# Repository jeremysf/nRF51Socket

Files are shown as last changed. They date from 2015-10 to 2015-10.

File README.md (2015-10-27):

# nRF51Socket
QFN48 socket to J-Link/JTAG 20-pin connector to program bootloaders, etc for Nordic nRF51.

I included a USB connector as an alternative to using the 5V power from the J-Link, but haven't had to use that yet, the power from the J-Link device works great!

I also included a 16mhz crystal in the design so that I could boot up the nRF51 and do some basic validation. Probably could get away without populating those or related components.

The socket is available on Amazon.com and Ebay.com for about $100 it's a QFN-48(52)BT-0.4-01 manufactured by Enplas.

![alt text]
(https://pbs.twimg.com/media/CR9HupoUYAArvvp.jpg)

![alt text]
(https://pbs.twimg.com/media/CR9HuqqVAAADbZV.jpg)

![alt text]
(https://pbs.twimg.com/media/CR9HuqIVAAAAnUr.jpg)

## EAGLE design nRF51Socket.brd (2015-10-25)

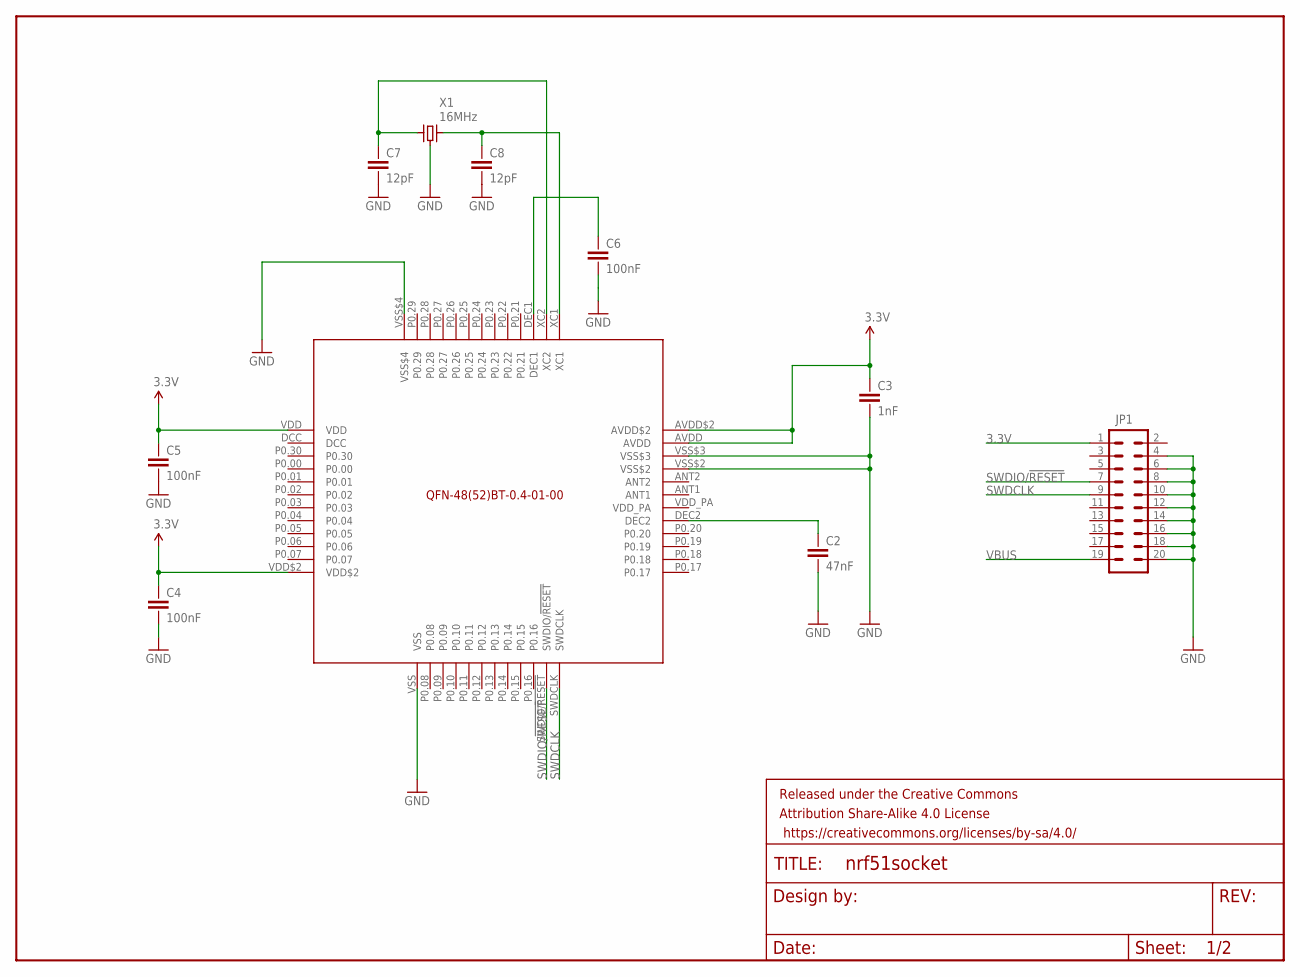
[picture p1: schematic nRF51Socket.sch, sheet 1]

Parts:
C2: 47nF; CAP-403
C3: 1nF; CAP-403
C4, C5, C6: 100nF; CAP-403
C7, C8: 12pF; CAP-403
FRAME1: FRAME-LETTERNO_PACKAGE; DUMMY
JP1: M10X2; 2X10
U1: QFN-48(52)BT-0.4-01-00
X1: 16MHz; CRYSTAL-2520

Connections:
3.3V: C3.2 (1), C4.2 (1), C5.2 (1), JP1.1, U1.AVDD, U1.AVDD$2, U1.VDD, U1.VDD$2; also elsewhere on the board
GND: C2.1 (2), C3.1 (2), C4.1 (2), C5.1 (2), C6.1 (2), C7.1 (2), C8.1 (2), JP1.4, JP1.6, JP1.8, JP1.10, JP1.12, JP1.14, JP1.16, JP1.18, JP1.20, U1.VSS, U1.VSS$2, U1.VSS$3, U1.VSS$4, X1.GND@1 (GND), X1.GND@2 (GND); also elsewhere on the board
unnamed: C2.2 (1), U1.DEC2
unnamed: C6.2 (1), U1.DEC1
unnamed: C8.2 (1), U1.XC1, X1.3
unnamed: C7.2 (1), U1.XC2, X1.1
SWDCLK: JP1.9, U1.SWDCLK
SWDIO/!RESET: JP1.7, U1.SWDIO/!RESET
VBUS: JP1.19; also elsewhere on the board

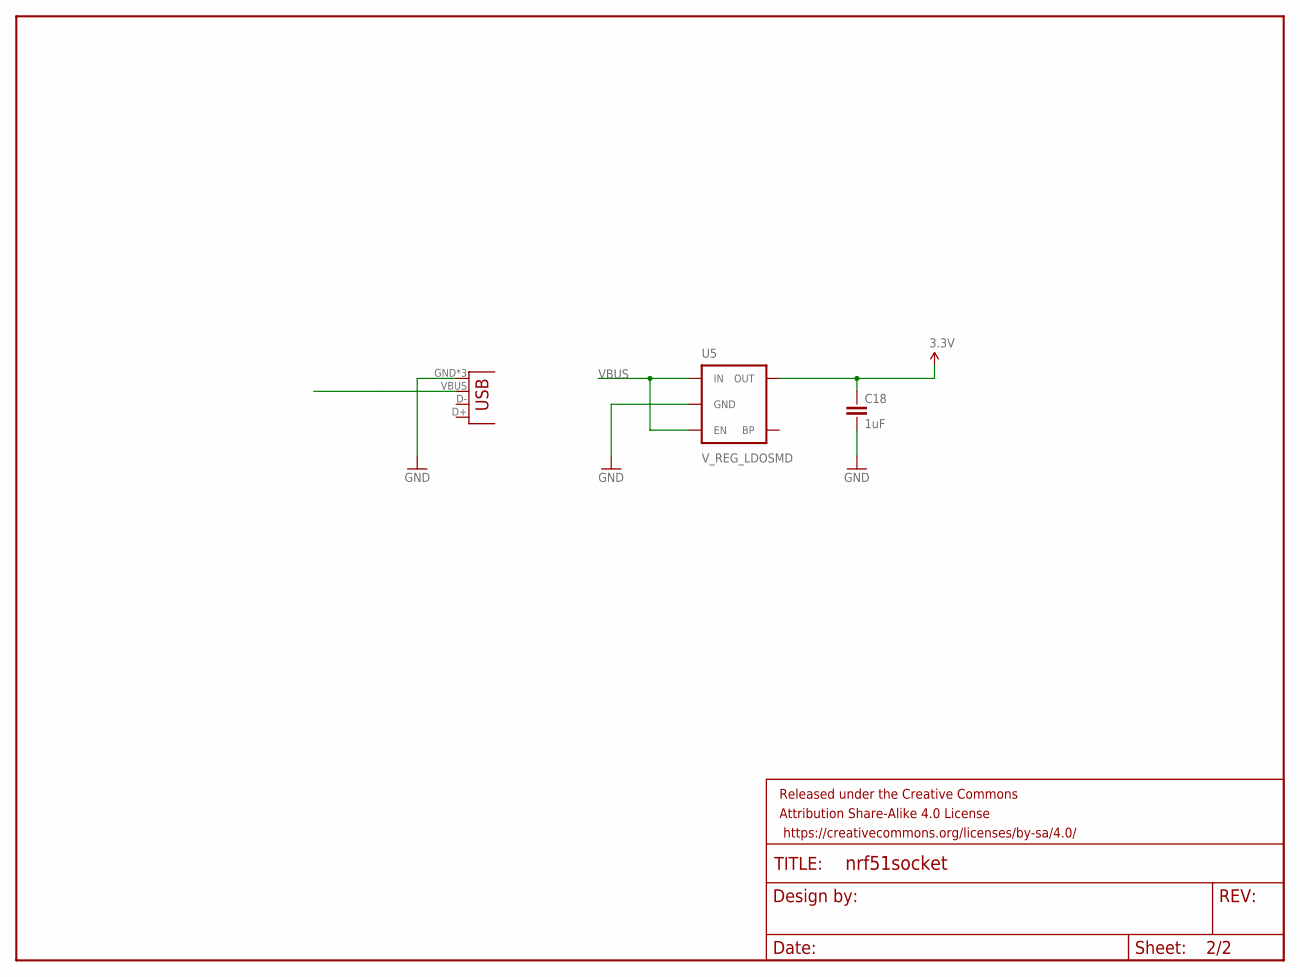
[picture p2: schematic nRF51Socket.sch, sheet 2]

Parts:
C18: 1uF; CAP-403
FRAME2: FRAME-LETTERNO_PACKAGE; DUMMY
JP2: USB-MICROB
U5: V_REG_LDOSMD; SOT23-5

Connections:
3.3V: C18.2 (1), U5.5 (OUT); also elsewhere on the board
GND: C18.1 (2), JP2.GND, JP2.MT1 (GND), JP2.MT2 (GND), U5.2 (GND); also elsewhere on the board
VBUS: JP2.VBUS, U5.1 (IN), U5.3 (EN); also elsewhere on the board

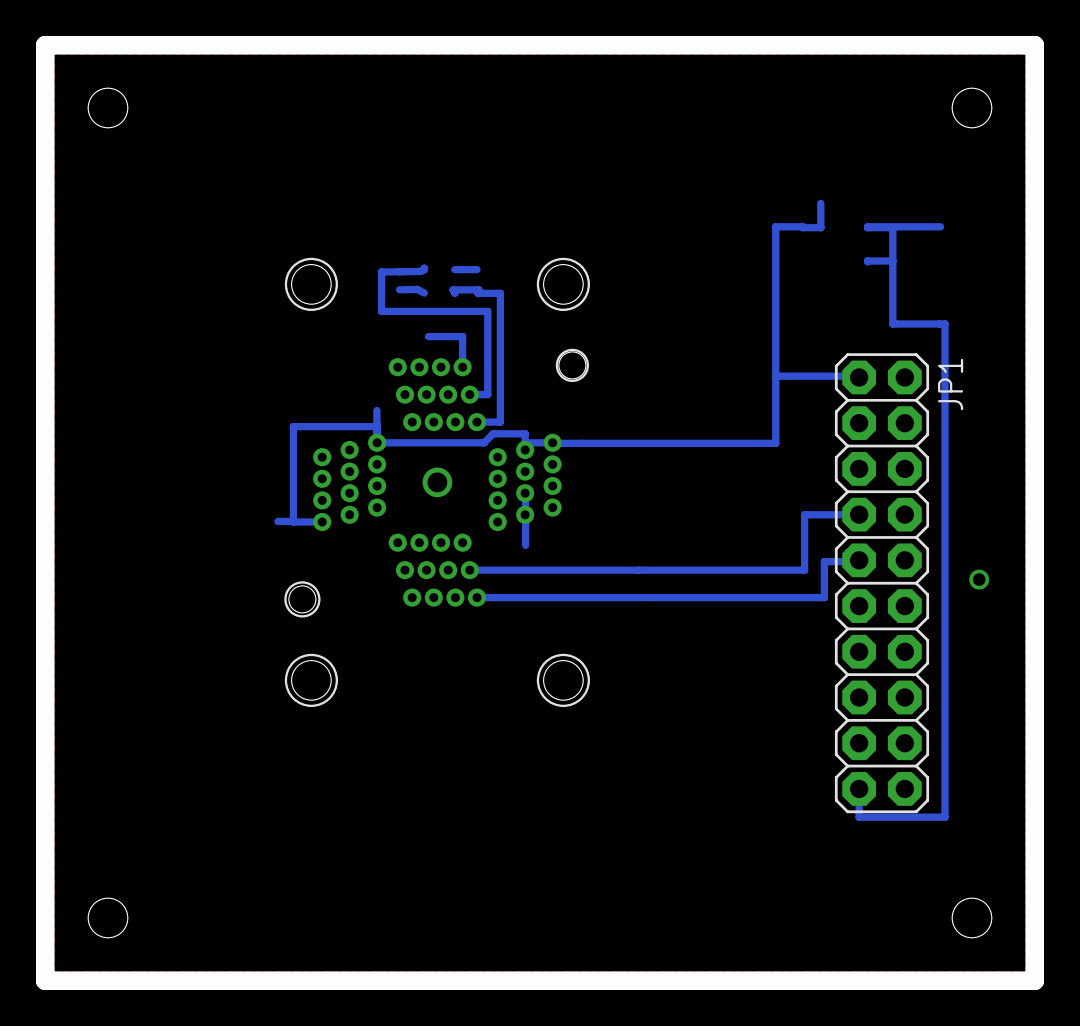
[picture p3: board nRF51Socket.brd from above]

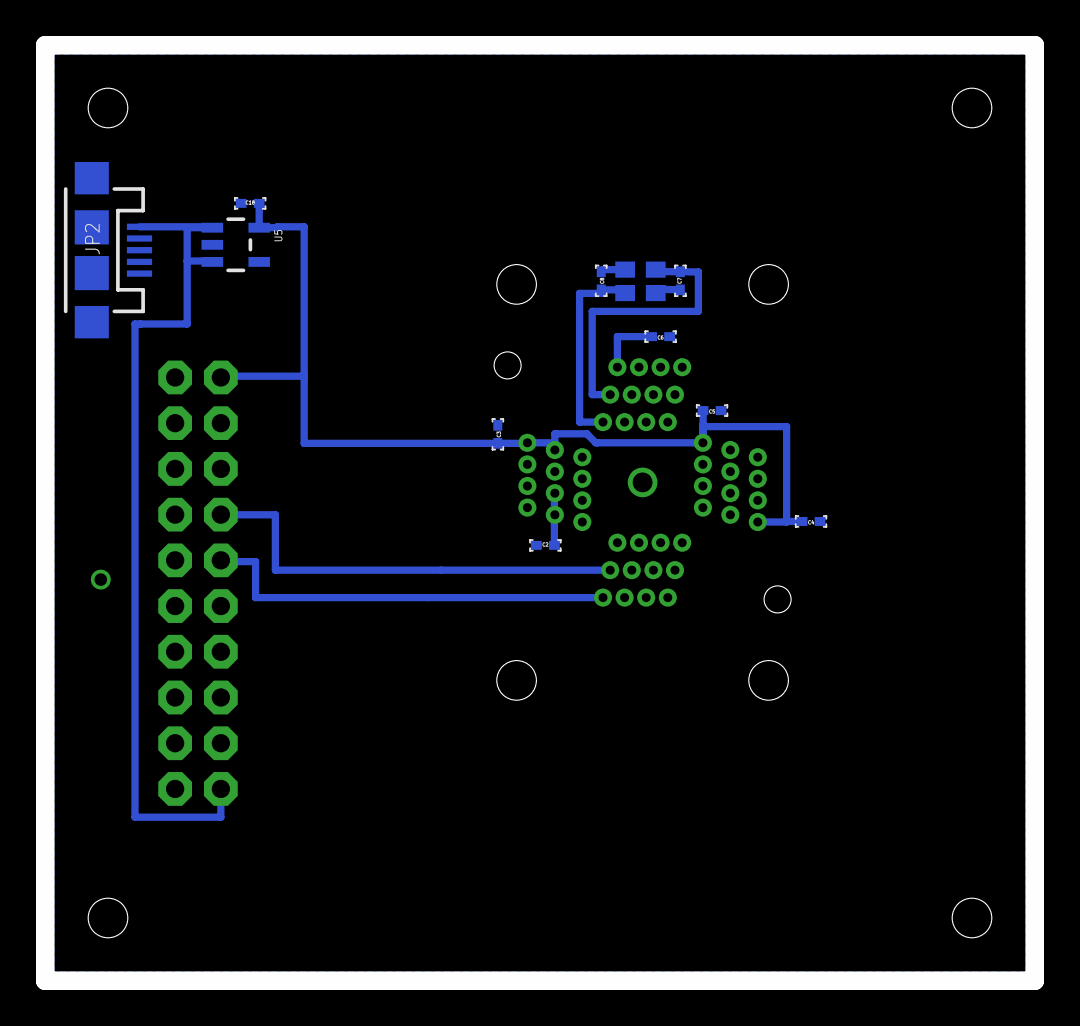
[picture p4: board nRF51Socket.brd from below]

Board: 2 copper layers, 55.0 x 52.0 mm, 15 parts (11 on the bottom side), 9 nets.

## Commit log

2015-10-21 Initial commit.
    [nRF51Socket.sch]
2015-10-21 First revison.
    [nRF51Socket.brd, nRF51Socket.sch]
2015-10-22 Changed to 20pin jtag socket.
    [nRF51Socket.brd, nRF51Socket.sch]
2015-10-25 More routable trace location.
    [nRF51Socket.brd]

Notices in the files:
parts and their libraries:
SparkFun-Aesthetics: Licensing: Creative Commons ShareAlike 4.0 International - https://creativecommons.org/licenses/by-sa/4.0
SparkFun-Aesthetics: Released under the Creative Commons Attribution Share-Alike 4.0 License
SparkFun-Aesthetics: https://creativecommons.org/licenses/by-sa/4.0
